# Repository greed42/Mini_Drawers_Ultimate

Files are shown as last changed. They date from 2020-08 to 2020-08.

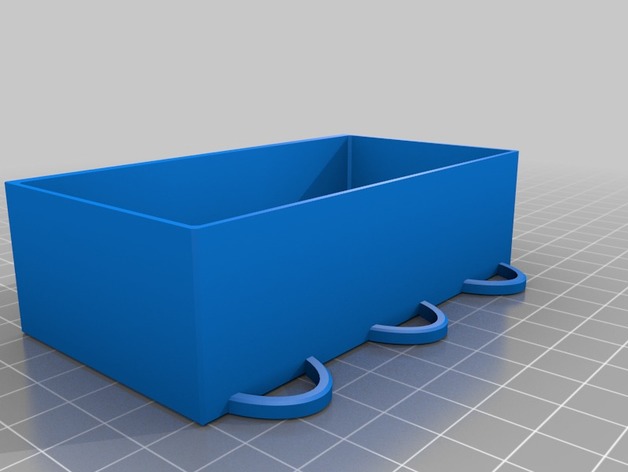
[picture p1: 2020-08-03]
images/7e2ca545eac1c5725b5ad3fc7ff9e364_preview_featured.jpg

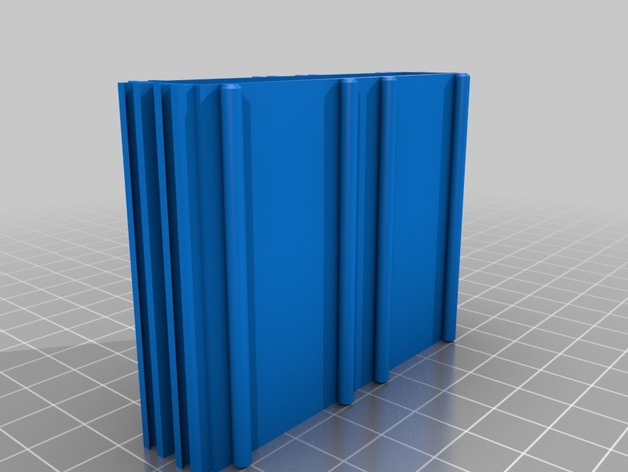
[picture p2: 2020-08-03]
images/3b2bb9709fd0cc8f3b78cd49e6e431dc_preview_featured.jpg

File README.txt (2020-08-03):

                   .:                     :,                                          
,:::::::: ::`      :::                   :::                                          
,:::::::: ::`      :::                   :::                                          
.,,:::,,, ::`.:,   ... .. .:,     .:. ..`... ..`   ..   .:,    .. ::  .::,     .:,`   
   ,::    :::::::  ::, :::::::  `:::::::.,:: :::  ::: .::::::  ::::: ::::::  .::::::  
   ,::    :::::::: ::, :::::::: ::::::::.,:: :::  ::: :::,:::, ::::: ::::::, :::::::: 
   ,::    :::  ::: ::, :::  :::`::.  :::.,::  ::,`::`:::   ::: :::  `::,`   :::   ::: 
   ,::    ::.  ::: ::, ::`  :::.::    ::.,::  :::::: ::::::::: ::`   :::::: ::::::::: 
   ,::    ::.  ::: ::, ::`  :::.::    ::.,::  .::::: ::::::::: ::`    ::::::::::::::: 
   ,::    ::.  ::: ::, ::`  ::: ::: `:::.,::   ::::  :::`  ,,, ::`  .::  :::.::.  ,,, 
   ,::    ::.  ::: ::, ::`  ::: ::::::::.,::   ::::   :::::::` ::`   ::::::: :::::::. 
   ,::    ::.  ::: ::, ::`  :::  :::::::`,::    ::.    :::::`  ::`   ::::::   :::::.  
                                ::,  ,::                               ``             
                                ::::::::                                              
                                 ::::::                                               
                                  `,,`

http://www.thingiverse.com/thing:1889761
Mini Drawers Ultimate by zeropage is licensed under the Creative Commons - Attribution - Non-Commercial - Share Alike license.
http://creativecommons.org/licenses/by-nc-sa/3.0/

# Summary

__What is this thing?__
This is a remix of TrevM's [Mini Drawers](http://www.thingiverse.com/thing:1621667 "Mini Drawers"). The original design is great but I needed some improvements. Thankfully, TrevM provides the *.scad-files, so the required changes could be made using OpenSCAD:

-     The runners did not fit perfectly in the slots. I think it depends on your 3D printer how snuggly these pieces fit together. I added a global variable "runnersDiameter" to the corresponding *.scad-files so adjusting the runner's diameters is quiet easy. I was fine with 2.85mm.

-   To prevent the drawers from falling out when pulling too far I added a small stopper on the top/front inside of the house.

-   Added magnet holes to the house's and drawer's backside. While the aforementioned stopper prevents pulling a drawer too far, the magnets prevent the drawer from sliding when a house is moved or tilted.

-   The handles were too delicate for my fingers so I made them oval and increased their protrusion.

-   To minimize elephant feet I added chamfers to the bottom of the drawer and handle using the [Chamfered primitives for OpenSCAD](https://github.com/SebiTimeWaster/Chamfers-for-OpenSCAD/ "Chamfered primitives for OpenSCAD") library by TimeWaster.

-  
Finally, a plethora of different sized houses and drawers is available. If the ones provided are not enough, read below in the Logbook how to create arbitrarily sized boxes.

See the chapter below for print instructions. And see the chapter post-printing on instructions for mounting the magnets (I used magnets similar to [these](https://www.aliexpress.com/item/50Pcs-8x1-Neodymium-Magnet-Disc-Permanent-N35-NdFeB-Small-Round-Super-Powerful-Strong-Magnetic-Magnets-8mm/32866508617.html) from AliExpress.)

Tell me if you need help or something specific!

__ __

__Logbook__
- *26.11.2017* -- Added new sizes 2x3 and the whole 3x1 .. 3x3 series. Mission complete.
- *09.10.2017* -- Reworked the filenames. Added missing houses/drawers like the 2x1 magnet versions. Added new sizes 1x3 and 2x2.
Right now, we have 1x1, 1x2, 1x3 as well as 2x1 and 2x2 houses and drawers each as a magnet and non-magnet version.✓ Soon I will add 2x3 as well as the whole 3x1..3 series, so there will be some big badda boom boxes available. For even bigger sizes or houses and drawers with slot-in magnets please use the Scad-files to produce the required STLs (see next Log-entry).

- *09.10.2017* -- Finally! Added three Scad-files that allow you to create arbitrarily sized houses and drawers with or without magnets *and* you can choose whether you have the standard glue-in magnet slots or -new!- drop-in magnet slots.
_All praise has to go to [@ofloveandhate](https://www.thingiverse.com/ofloveandhate/about) who rewrote the original code to enable the aforementioned parametrizations. Dani, thanks a lot!_
Please note that this is work in progress and that you need to use OpenScad to create your own STL-files!
How to: Use "assembly.scad" to produce a house and an accompanying drawer at the same time. Very important: If you choose drop-in magnets, you *must* edit the "house.scad" and uncomment a couple of lines of code. Read the comments carefully.

- *24.05.2017* -- Added a 1x1 drawer with three slots (magnet and non-magnet version).

- *09.05.2017* -- Added a 2x1 house and drawer. Thanks to Elerion for beta printing! And a good tip from Elerion for those whose printers produce drawers that are too tightly fitting: Reduce the drawers' sizes by 1% on the X and Z axes. Magnet versions of the 2x1 set tbd.

- *23.01.2017* -- My drawers glided too easily in their houses with the result that they tended to slide open when my drawer phalanx was (accidentally) touched. Or, much worse, nuts, screws, and other stuff got spilled over my table. Since I already printed a lot of houses and drawers, I underwent the pain to drill a plethora of 8mm holes to glue 8mm x 1mm magnets to the backside of the houses and drawers. See [this video](https://youtu.be/GgcQiEWDeZY) how the houses/drawers with magnets work and look like.
To ease things for the future, all MD Ultimate files are now available in two versions: With and without holes for 8mm x 1mm magnets! (I used [these](https://www.aliexpress.com/item/50Pcs-Silver-N35-Super-Strong-Round-Disc-8mm-X-1mm-Rare-Earth-Neodymium-magnet/32704942674.html) magnets from AliExpress.)

- *31.12.2016* -- A double sized drawer with divider was missing. masterman274 was so kind to provide [this one](http://www.thingiverse.com/thing:2006275). Thank you! (Please note that I added an according drawer in the meantime while dealing with the magnet stuff; cf. above.)

-
*15.11.2016* -- Added a drawer with two slots.

# Print Settings

Printer Brand: Ultimaker
Printer: Ultimaker 2
Resolution: 0.16mm
Infill: 0%

Notes: 
Some notes on printing: I tried a lot of different settings (in Cura) to optimise quality and print speed. My best settings with a 0.4mm nozzle so far:

- Layer height 0.16mm
- Shell thickness 0.4 mm
- Bottom/top thickness 0.8mm
- Fill density 0% (yes, zero!)
- Print speed 70 mm/s
- no support, no brim

A word on zero infill: Since neither the houses nor the drawers will -in most cases- experience a lot of stress they, thus, do not need to be rock solid. Using zero infill with a shell thickness of 0.4mm is kind of spiralizing the inner and outer walls and only filling the top and bottom. This results in reduced printing times and a sufficient strength.

# Post-Printing

## How to attach the magnets

If you printed houses and drawers with mounting holes for magnets you might ask yourself how to attach the magnets to these holes.

I put a drop of super glue on the rim of a magnet, laid it down on my workbench, then imposed the house (or drawer) on the magnet. This way, the magnet and the house or drawer will be on level. Take care that leaking super glue may glue your house or drawer to the workbench. To avoid this I moved the house or drawer in a circular motion. Just long enough until the magnet was sufficiently sticking to the house or drawer.

Another option might be to put a drop of hot glue on the magnet, then impose the house or drawer on the magnet. Hot glue allows minor corrections by gently heating up the glue. Nonetheless, take care not to take too much hot glue since you do not want the glue to get in the way with the drawer.

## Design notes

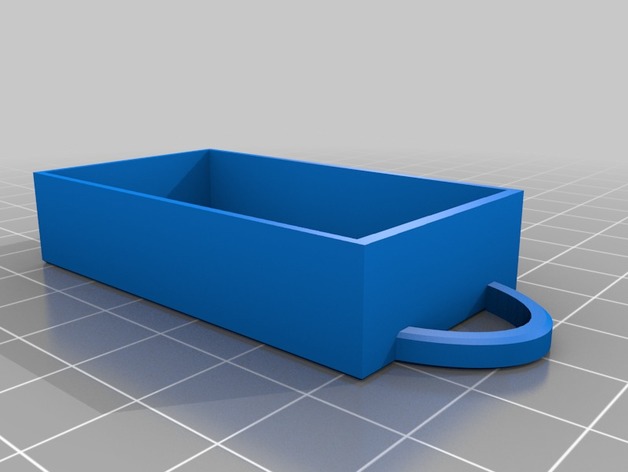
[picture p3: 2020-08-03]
images/46b5443ca9f86b0492274a63288024b4_preview_featured.jpg

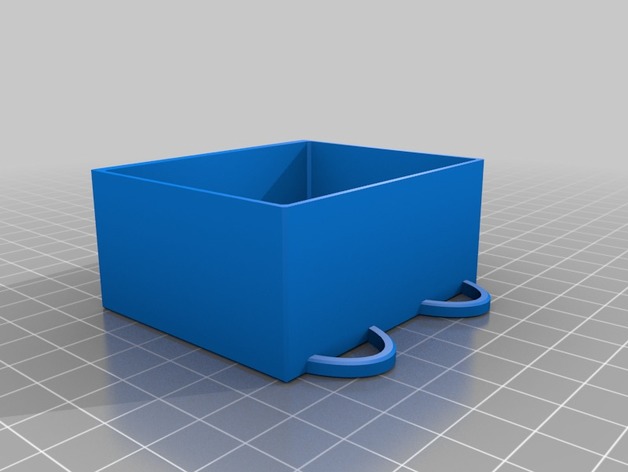
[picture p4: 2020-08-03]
images/7ca578415db62366bc3f32fe54b87f35_preview_featured.jpg

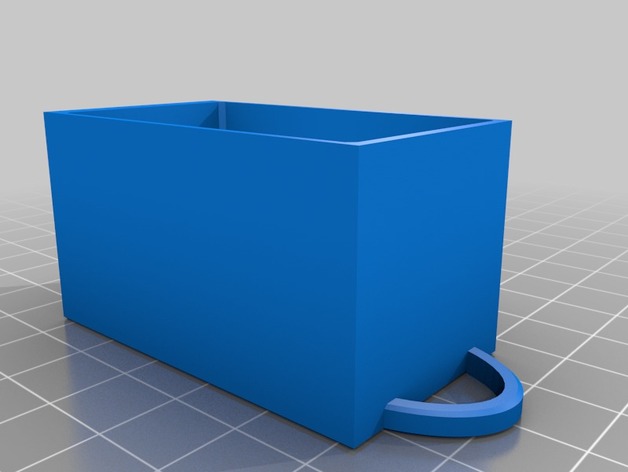
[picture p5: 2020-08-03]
images/18cb1cac1b9d0c3dc831ad14e947cb29_preview_featured.jpg

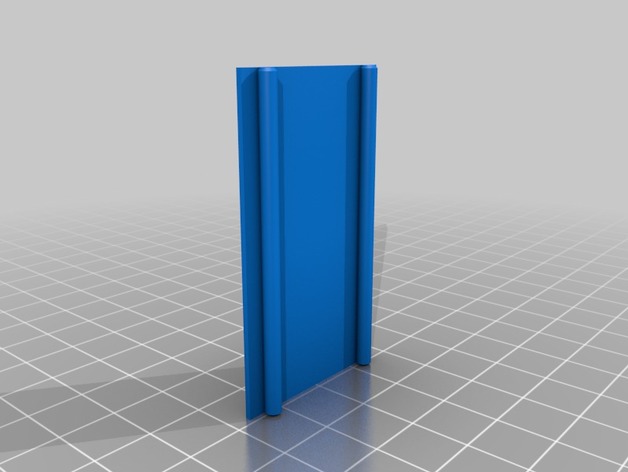
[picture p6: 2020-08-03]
images/90e3aa6325cb6bdf091ba50e56fa240c_preview_featured.jpg

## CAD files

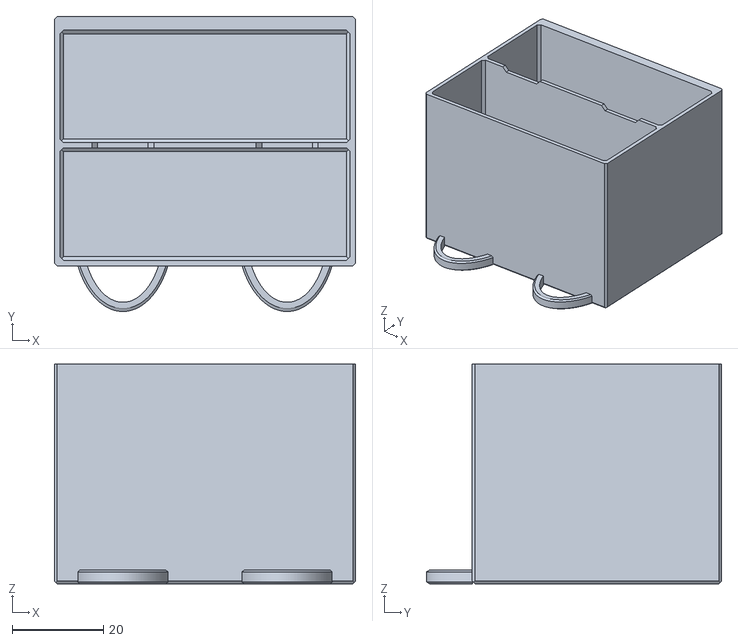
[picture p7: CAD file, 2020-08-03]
files/2x3_Drawer_-_two_slots_magnet.stl
65.9 x 64.5 x 48.0

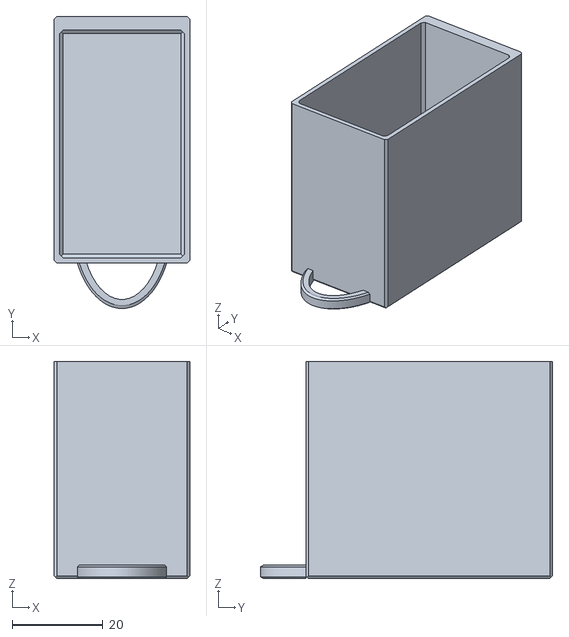
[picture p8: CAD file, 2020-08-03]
files/1x3_Drawer_magnet.stl
30.0 x 64.5 x 48.0

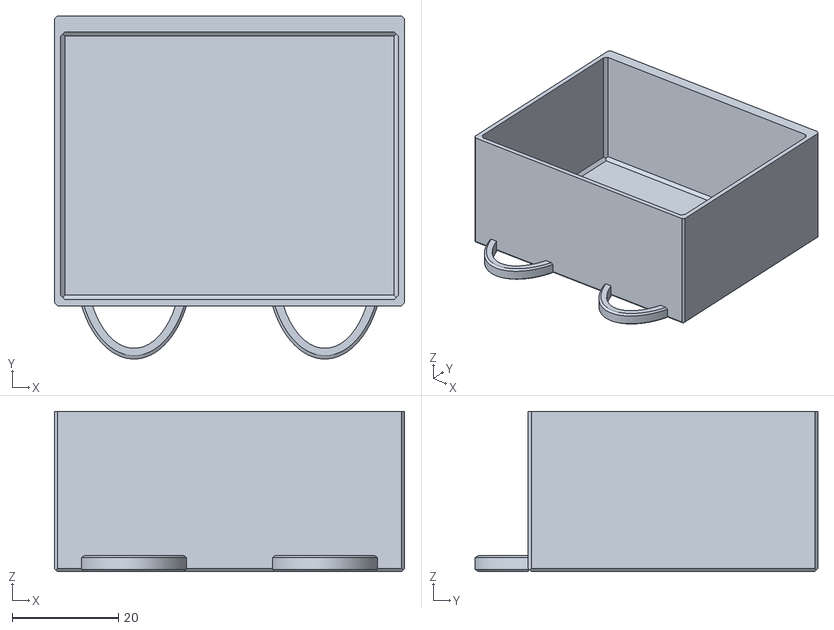
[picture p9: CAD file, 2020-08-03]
files/2x2_Drawer.stl
65.9 x 64.5 x 30.1

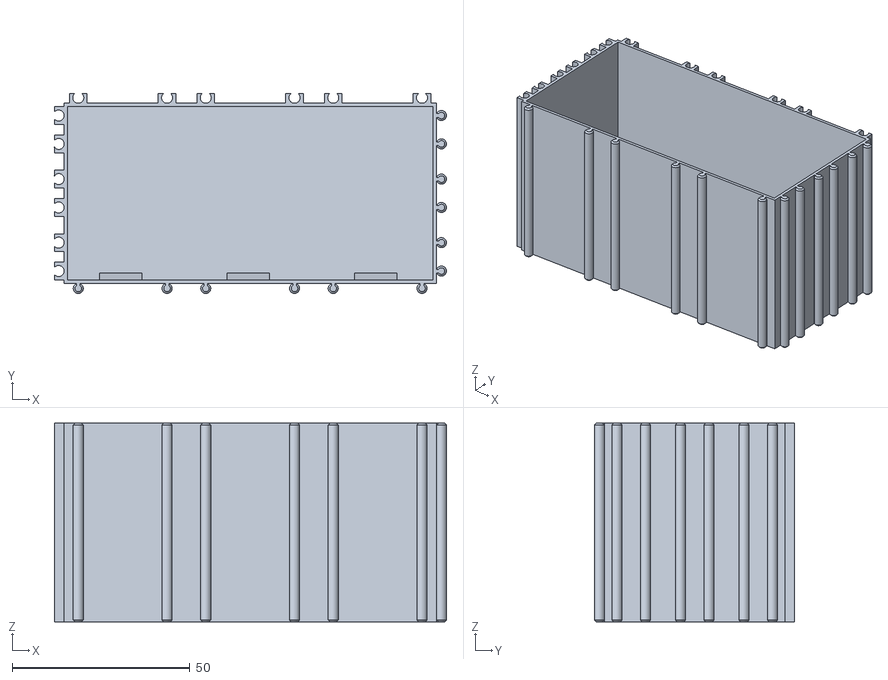
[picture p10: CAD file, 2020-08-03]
files/3x3_House.stl
110.4 x 56.3 x 56.0

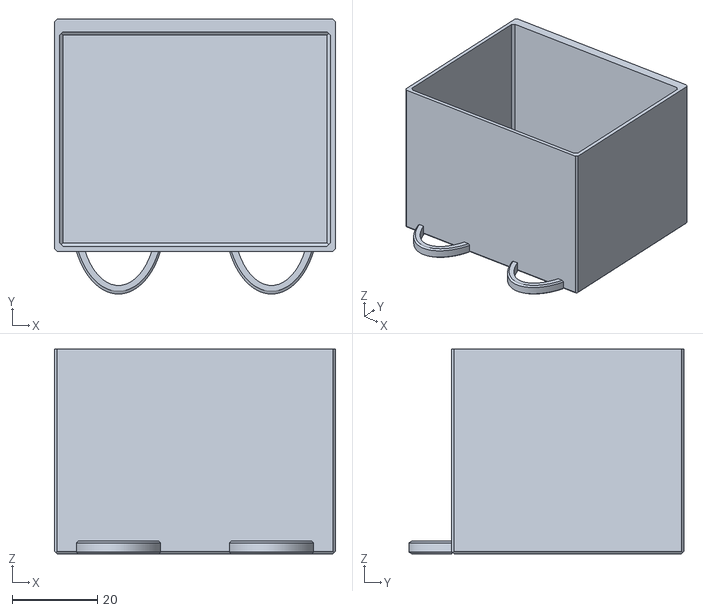
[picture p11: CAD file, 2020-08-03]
files/2x3_Drawer_magnet.stl
65.9 x 64.5 x 48.0

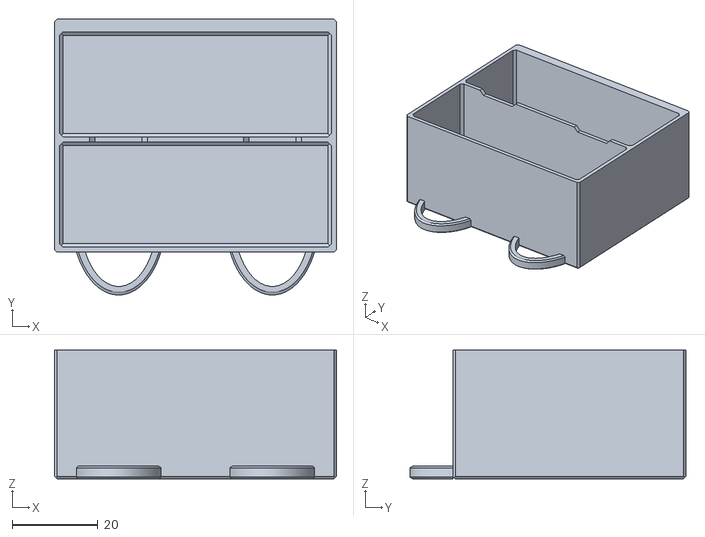
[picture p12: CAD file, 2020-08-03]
files/2x2_Drawer_-_two_slots.stl
65.9 x 64.5 x 30.1

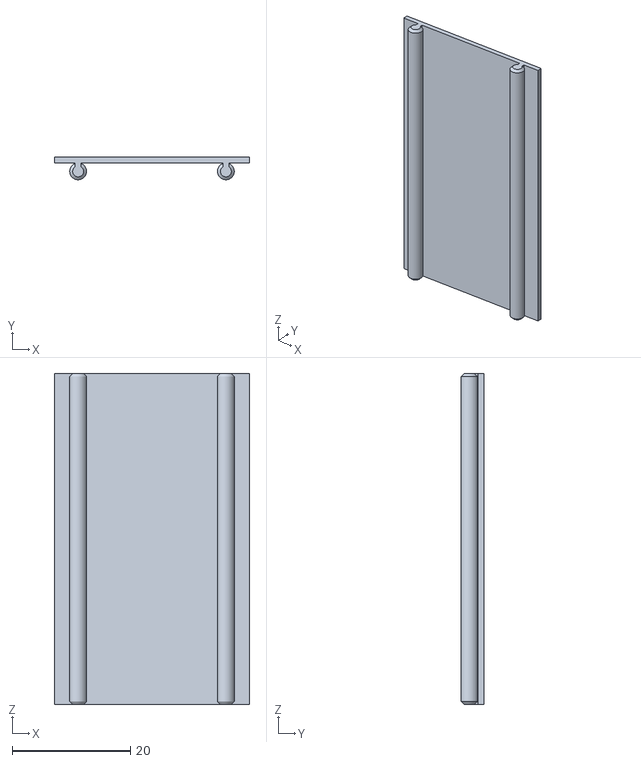
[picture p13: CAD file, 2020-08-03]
files/1x1_House_-_bottom_plate.stl
33.0 x 3.82 x 56.0

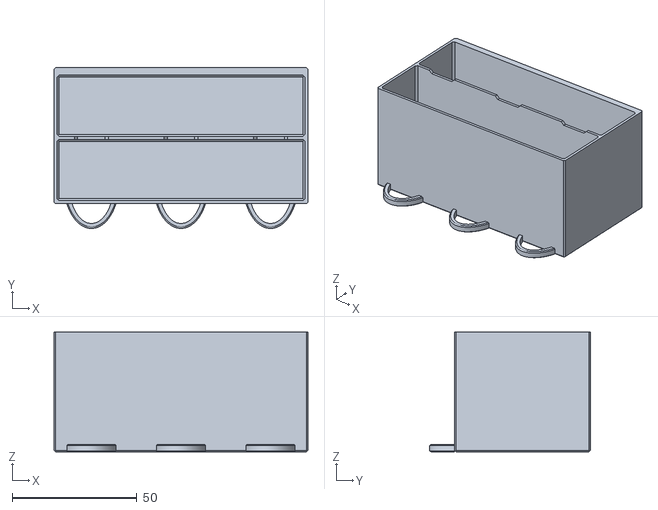
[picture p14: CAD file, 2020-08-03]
files/3x3_Drawer_-_two_slots.stl
101.8 x 64.5 x 48.0

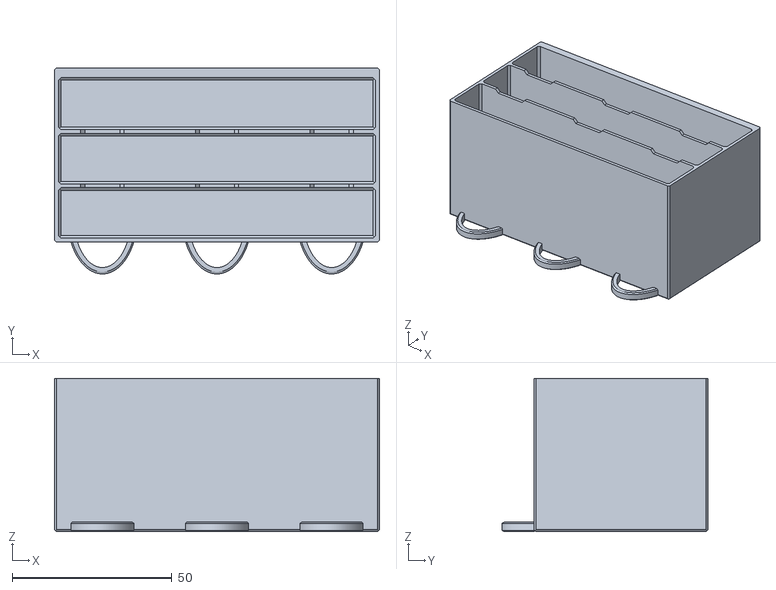
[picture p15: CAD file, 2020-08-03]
files/3x3_Drawer_-_three_slots_magnet.stl
101.8 x 64.5 x 48.0

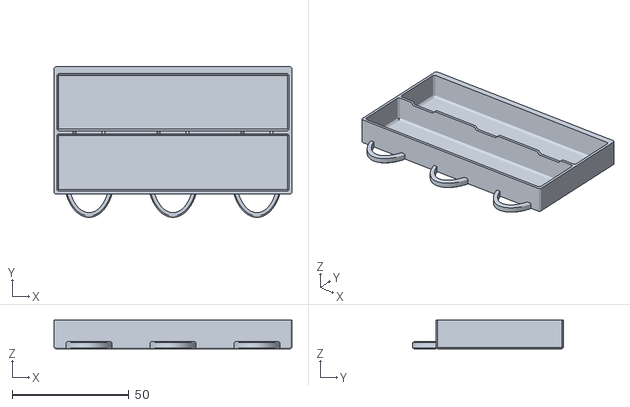
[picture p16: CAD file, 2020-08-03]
files/3x1_Drawer_-_two_slots.stl
101.8 x 64.5 x 12.2

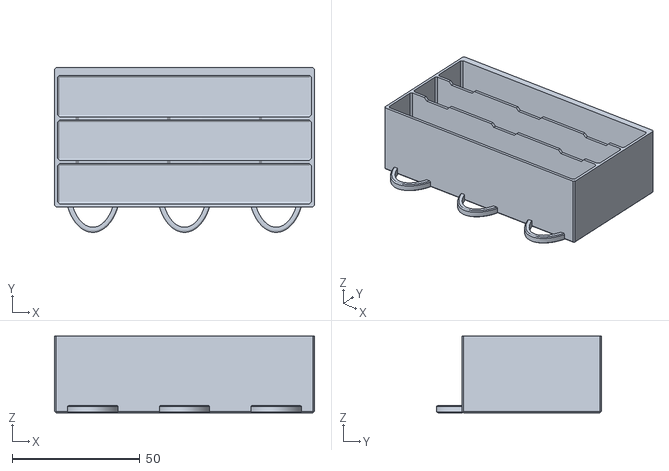
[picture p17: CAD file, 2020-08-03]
files/3x2_Drawer_-_three_slots_magnet.stl
101.8 x 64.5 x 30.1

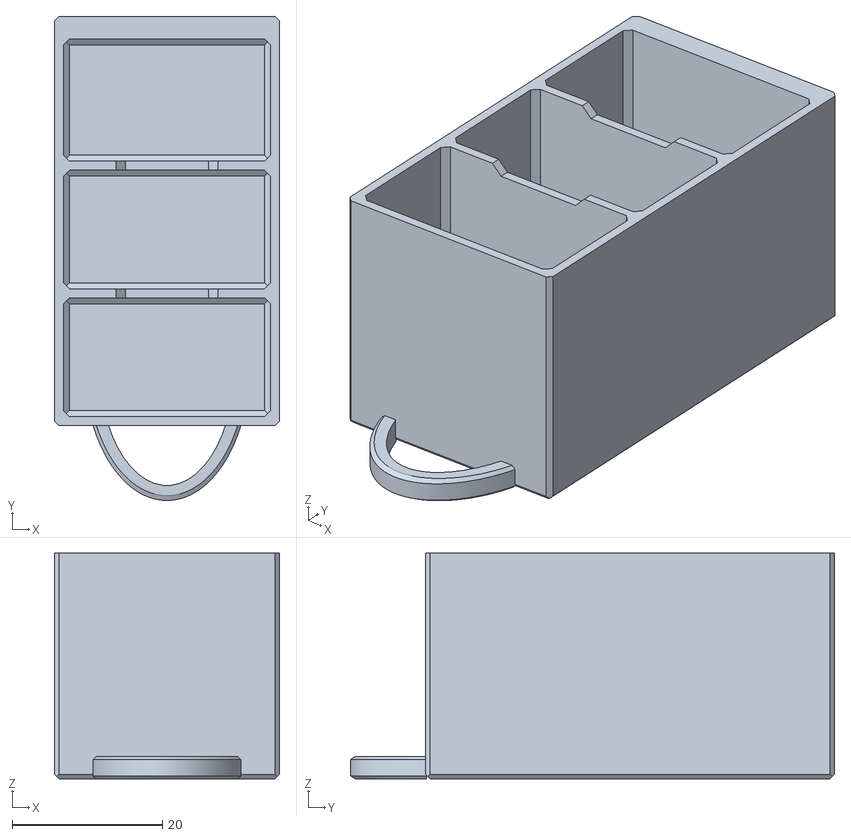
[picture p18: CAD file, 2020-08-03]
files/1x2_Drawer_-_three_slots_magnet.stl
30.0 x 64.5 x 30.1

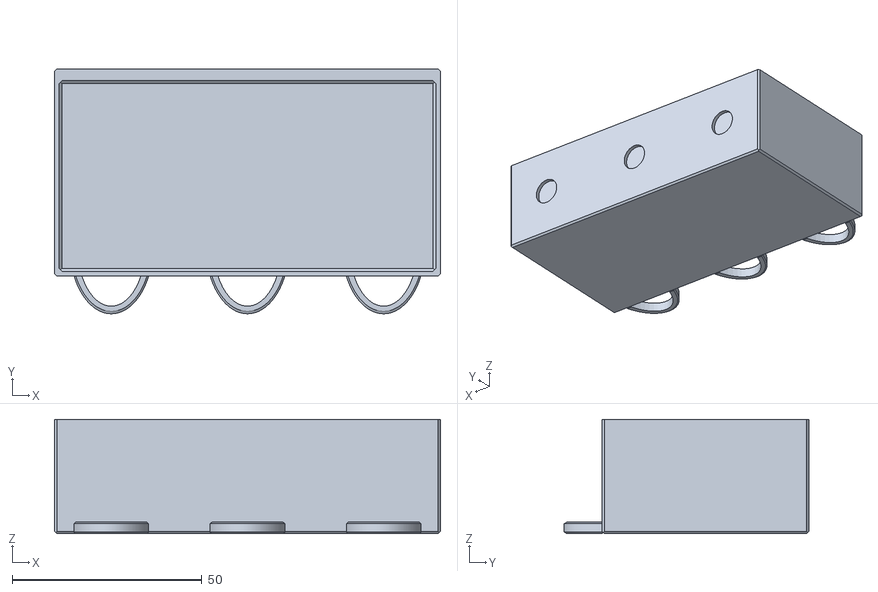
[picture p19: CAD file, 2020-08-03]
files/3x2_Drawer_magnet.stl
101.8 x 64.5 x 30.1

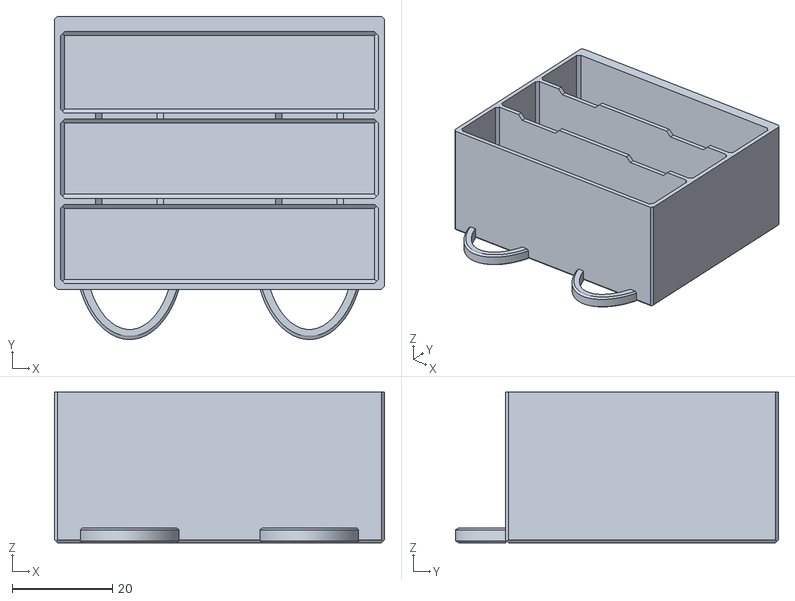
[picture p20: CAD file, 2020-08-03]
files/2x2_Drawer_-_three_slots.stl
65.9 x 64.5 x 30.1

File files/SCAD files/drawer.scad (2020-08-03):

// scad code for modular minidrawer -- drawer part
// code originally by zeropage. rewritten by ofloveandhate sep2017

include <Chamfer.scad>; // https://github.com/SebiTimeWaster/Chamfers-for-OpenSCAD/

drawer_label = ["test",4,"Liberation Sans:style=Bold",0.5];
use_label = true;

$fn = 50;
ang = 25;

// ======= EDIT ======================
num_x = 1;
num_y = 2;
slot_partition = [.33,.33, .34];//[0.4,0.6]; // partition of 1 into slots
use_magnet = false;
magnet_is_droppedin = false;
// ===================================

// ideally these numbers come directly from the house parameters.
house_wall_thickness_s = 1;
house_wall_thickness_b = 1;
house_depth = 56;
unit_height = 17.9;
unit_width = 35.9;
space_width = 4.9;
space_height = 4.9;


// thicknesses of things
drawer_wall_thickness_x = 1.2;
drawer_wall_thickness_f = 1.2;
drawer_wall_thickness_b = 3; // shoule be thicker than magnet_h plus extrusions, if using slot for magnet
drawer_wall_thickness_s = 1.2; // thickness of walls between slots
drawer_floor_thickness = 1;

// space to leave between the walls of the drawer and house
inset_width = 0.5;
inset_height = 0.6;
inset_depth = 0.5;



chamfer_interior = 0.8;
chamfer_exterior = 0.6;
should_chamfer_top = 0; // a boolean 1 or 0

magnet_r = 4.15;
magnet_h = 1.25;

use_num_x_handles = true; // false generates a single handles in the middle

eps = 0.01;





to_print = true;

if (to_print)
{
  translate([0,-drawer_depth-10,0])
  drawer();
}
else
  ;


module drawer()
{
  difference()
  {
    drawer_positive();
    drawer_negative();
  }

  handles(); 
}

drawer_depth = house_depth - 1*house_wall_thickness_b - inset_depth;// including walls
drawer_width = unit_width*num_x -space_width - 2*inset_width;
drawer_height = unit_height*num_y - space_height+0.8 - inset_height;

module drawer_positive()
{
  usable_height = drawer_height - drawer_floor_thickness;
  chamferCube(drawer_width,drawer_depth,usable_height,chamfer_exterior,[1,1,should_chamfer_top,should_chamfer_top],[1,should_chamfer_top,should_chamfer_top,1],[1,1,1,1]); 
  if ( use_label ) label();
}

module drawer_negative()
{

  num_slots = len(slot_partition);

  interior_w = drawer_width - 2*drawer_wall_thickness_x;

  x = drawer_wall_thickness_f;

  usable_depth = drawer_depth - drawer_wall_thickness_f - drawer_wall_thickness_b - (
  num_slots-1)*drawer_wall_thickness_s;

  usable_height = drawer_height - drawer_floor_thickness;

  for (ii = [0:num_slots-1])
  {
    depth_this = slot_partition[ii]*usable_depth;
    y_this = 0;
    used_prev = add(slot_partition, 0, num_slots-ii);
    bla = used_prev*usable_depth+ii*drawer_wall_thickness_s + drawer_wall_thickness_f;

    translate([drawer_wall_thickness_x,bla,drawer_floor_thickness])
      chamferCube(interior_w,depth_this,usable_height,chamfer_interior,[1,1,0,0],[1,0,0,1],[1,1,1,1]);
  }

  if (num_slots>1)
  {
    for (jj = [0:num_x-1]){
      for (ii = [1:num_slots-1])
      {
        depth_this = slot_partition[ii]*usable_depth;
        y_this = 0;
        used_prev = add(slot_partition, 0, num_slots-ii);
        //		echo(used_prev);
        bla = used_prev*usable_depth+ii*drawer_wall_thickness_s + drawer_wall_thickness_f - drawer_wall_thickness_s*1.5;
        //drawer_width/(num_x)*(jj) + 14/2
        translate([8 +jj*35.9,bla,usable_height-1.29])
        {
          chamferCube(14,2,1.3,1.5,[],[1,0,0,1],[]);
        }
      } // for ii
    } // jj
  } // if
  if (use_magnet)
    drawer_magnet_cutouts();
}

function add(cont, ii=0, off_b=0, val=0) = ii<len(cont)-off_b ? add(cont, ii+1, off_b, val+cont[ii]) : val;

module drawer_magnet_cutouts()
{
  for (ii = [0:num_x-1])
  {
    if (magnet_is_droppedin)
      translate([ii*35.9+15,drawer_depth - drawer_wall_thickness_b/2-magnet_h/2,0])
        drawer_magnet_cutout_single();
    else
      translate([ii*35.9+15,drawer_depth-magnet_h+eps,0])
        drawer_magnet_cutout_single();
  }	
}



module drawer_magnet_cutout_single()
{
  translate([0,0,drawer_height/2]) 
  {
    translate([0,0,0])
      rotate([-90,0,0]) cylinder(h=magnet_h+eps,r=magnet_r,$fn=100); // top hole for magnet
    if (magnet_is_droppedin)
      translate([-magnet_r,-eps,0])
        cube([magnet_r*2, magnet_h+2*eps, drawer_height/2]); // top hole for magnet
  }

}

module handles()
{
  if (use_num_x_handles)
  for (ii=[0:num_x-1])
    translate([ii*35.9+15,0,0])
      handle();
  
  else
     translate([drawer_width/2,0,0])
      handle();
}


module handle()
{
  difference() {
    translate([0,8,0]) chamferOval(11,18,3);
    translate([0,8,-0.1]) oval(9,16,3.2);
    translate([-11-2,0.1,-0.1])	cube([29.8,30,3.2]);
  }
}

module oval(w,h, height, center = false) {
  scale([1, h/w, 1]) cylinder(h=height, r=w, center=center);
}

module chamferOval(w,h, height) {
  scale([1, h/w, 1]) chamferCylinder(height, w, w, .4, 360,1);
}


module label()
{
/* original code from dani      translate([drawer_width/2-len(drawer_label[0])/2*drawer_label[1]*0.6,0,drawer_height/2])
    rotate([90,0,0])
      linear_extrude(height=drawer_label[3])
        text(drawer_label[0], font=drawer_label[2], size=drawer_label[1]);
*/    
/* as suggested by Bolukan */
translate([drawer_width/2,0,drawer_height/2+0.75])
rotate([90,0,0])
linear_extrude(height=drawer_label[3])
text(drawer_label[0], font=drawer_label[2], size=drawer_label[1], halign="center", valign="center");    
}

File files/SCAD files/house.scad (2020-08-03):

// scad code for modular minidrawer -- house part
// code originally by zeropage. rewritten by ofloveandhate sep2017

include <Chamfer.scad>; // https://github.com/SebiTimeWaster/Chamfers-for-OpenSCAD/
$fn = 50;
house_wall_thickness_b = 1;
house_depth = 56; // in millimeters. this is the depth of the unit against the wall, front to back, including walls.

// ======= EDIT ================
num_x = 2;  // width
num_y = 2;  // height
use_magnet = false; // true to use magnets
//magnet_is_droppedin = true; // true to get drop-in slot for the magnet
//house_wall_thickness_b = 2; // MUST uncomment if drop-in magnets used, else the backwall will be too thin
//house_depth = 57; // MUST uncomment if drop-in magnets used, else the drawers will stand out by 1mm
magnet_r = 4.15;
magnet_h = 1.25; // the back wall should be at least this thick if using dropped in magnet
// ===============================

house_wall_thickness_s = 1;

interior_unit_width = 35.9;
interior_unit_height = 17.9;

chamfer_runners = 0.5;
runnersDiameter = 2.85;
runner_joincube_width = 1;

slot_thickness = 2.8;
slot_width = 5;
slot_gap = 0.25 ; // extra space between the runner cylinder, and the slot receiver. this number is a difference in diameters, so this difference is NOT the total gap all around, that's half this number.
slot_cylinder_inset = 0.1;
slot_inset_from_box_x = 1.5;
slot_inset_from_box_y = 1;

runner_offset_x = 25;
runner_offset_y = 8;

stopper_height = 2;  // how far off the top wall the stopper should project
stopper_length = 10;
stopper_width = 10;
stopper_inset = 2;
stopper_faces_front = false;  // which side the flat face of the stoppers should be on.  if true, the flat face is toward the front of the housing.


eps = 0.01;

to_print = true;




///////////utility computations

inter_house_offset = house_wall_thickness_s*2 + runnersDiameter; // 4.9 is old version
house_box_height = num_y*interior_unit_height - inter_house_offset; 
house_box_width = num_x*interior_unit_width - inter_house_offset; 
inter_drawer_offset = (runnersDiameter+slot_gap/2);

////////////  end utility computations


if (to_print)
  house();
else
{
//  house(); // display mode in the assembly

//  translate([-house_box_width - inter_house_offset,0,0])
//    house();
//
//  translate([house_box_width + inter_house_offset,0,0])
//    house();
//
//  translate([0,-house_box_height - inter_house_offset,0])
//    house();
//
//  translate([0,+house_box_height + inter_house_offset,0])
//    house();
}

module house()
{
  difference() {
    house_positive();
    house_negative();
  }
}


module house_negative()
{
  q = house_wall_thickness_s*2 + runnersDiameter; // 4.9 for 100% compatibility w old versions
  difference(){
    translate([house_wall_thickness_s,house_wall_thickness_s,house_wall_thickness_b])
      cube([interior_unit_width*num_x-q, interior_unit_height*num_y-q, house_depth]);
    stoppers();
  }
  if (use_magnet)
    house_magnet_cutouts();
}


module house_magnet_cutouts()
{
  if (magnet_h >= 1*house_wall_thickness_b && magnet_is_droppedin)
  {
    echo("magnet thickness very near to back wall thickness.  things probably not as desired");
  }

  for (ii = [0:num_x-1])
  {
    if (magnet_is_droppedin)
    {
      translate([ii*interior_unit_width+16,0,house_wall_thickness_b/2-magnet_h/2])
        magnet_cutout_single();
    }
    else
    {
      translate([ii*interior_unit_width+16,0,house_wall_thickness_b-magnet_h])
        magnet_cutout_single();
    }
  }	
}



module magnet_cutout_single()
{
  translate([0,house_box_height/2, 0 ])
  {
    magnet();
    if (magnet_is_droppedin)
    {
      magnet_cutout_slot();
    }
  }
}

module magnet()
{
  translate([0,0,0])
    rotate([0,0,0]) cylinder(h=magnet_h+eps,r=magnet_r,$fn=100);
}

module magnet_cutout_slot()
{
  c = house_box_height/2+2*eps;
  translate([-magnet_r,-house_box_height/2-eps,0])
    cube([magnet_r*2, c , magnet_h+eps ]); // top hole for magnet
  // the eps here are to ensure the cube protrudes from the top of the house
}



module stoppers()
{
for (ii = [0:num_x-1])
  translate([ii*interior_unit_width,0,0]) 
    stopper();
}

module stopper()
{
  translate([stopper_width,stopper_height+house_wall_thickness_s-eps,house_depth-stopper_inset]) 
    rotate( [0,180,180] ) 
      prism(l=stopper_length+stopper_height,w=stopper_height,h=stopper_length);
}



module house_positive()
{
  q = runnersDiameter; // 2.9 for 100% compatibility with old versions, though the difference is quite small (0.05)

  overall_x = interior_unit_width*num_x-q;
  overall_y = interior_unit_height*num_y-q;
  cube([overall_x, overall_y,house_depth]); 

  radius = runnersDiameter/2;

  for (ii=[0:num_x-1])
    translate([interior_unit_width*ii,0,0])
    {
      runner_bottom();
      translate([runner_offset_x, 0, 0])
        runner_bottom(); 

      translate([0,overall_y-interior_unit_height+q,0])
      {
        slot_top();
        translate([runner_offset_x,0,0])
          slot_top();
      }
    }

  for (jj=[0:num_y-1])
    translate([0,interior_unit_height*jj,0])
    {
      translate([overall_x-(interior_unit_width-runnersDiameter),0,0])
      {
        runner_right();
        translate([0,8,0])
          runner_right(); 
      }
      translate([0,0,0])
      {
        slot_left();
        translate([0,runner_offset_y,0])
          slot_left();
      }
    } // for jj's translate

}




module slot_top()
{
  slot_diameter = runnersDiameter + slot_gap;
  difference()
  {
    translate([ slot_inset_from_box_x,  15-slot_cylinder_inset, 0]) cube([slot_width,slot_thickness,house_depth]);
    translate([ (slot_width/2+slot_inset_from_box_x),  16.5, -eps]) cylinder(d=slot_diameter,h=house_depth+2*eps);
  }
}

module runner_bottom()
{
  runner_cylinder_inset_bottom = 0.025;
  radius = runnersDiameter/2;

  x = slot_width/2+slot_inset_from_box_x;
  y = radius-runner_cylinder_inset_bottom;

  translate([ x,  -y, 0]) chamferCylinder(house_depth,radius,radius,chamfer_runners);
  translate([x-runner_joincube_width/2,-(y-eps), 0]) cube([runner_joincube_width,radius,house_depth]);
}


module slot_left()
{
  slot_diameter = runnersDiameter + slot_gap;
  translate([0,0,0])
  difference()
  {
    q = runnersDiameter/2+slot_cylinder_inset;
    translate([- (slot_thickness - slot_cylinder_inset),   slot_inset_from_box_y,   0]) cube([slot_thickness,slot_width,house_depth]);
    translate([-q, slot_inset_from_box_y + slot_width/2, -eps]) cylinder(d=slot_diameter,h=house_depth+2*eps);
  }

}


module runner_right()
{

  radius = runnersDiameter/2;
  translate([(interior_unit_width-runnersDiameter/2), slot_inset_from_box_y + slot_width/2,0]) chamferCylinder(house_depth,radius,radius,chamfer_runners);

  x = (interior_unit_width-runnersDiameter)-eps;
  y = slot_inset_from_box_y + slot_width/2-runner_joincube_width/2;
  translate([x, y,  0]) cube([radius,runner_joincube_width,house_depth]);
}







module prism(l, w, h)
{
  p_front = [[0,0,0], [l,0,0], [l,w,0], [0,w,0], [0,w,h], [l,w,h]];
  p_back = [[0,0,h], [l,0,h], [l,w,0], [0,w,0], [0,w,h], [l,w,h]];

  f = [[0,1,2,3],[5,4,3,2],[0,4,5,1],[0,3,4],[5,2,1]];

  if (stopper_faces_front)
  {
    polyhedron(
      points=p_front,
      faces=f
    ); 
  }
  else
  {
    polyhedron(
      points=p_back,
      faces=f
    ); 
  }

}

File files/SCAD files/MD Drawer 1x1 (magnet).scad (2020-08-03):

include <Chamfer.scad>;

$fn = 50;
ang = 25;

translate([ -15,0,0]) drawer0();

module drawer0()
{
  difference() {
	chamferCube(30.4,54.1,12.4,.4,[1,1,0,0],[1,0,0,1],[]);
    translate([1,1.5,1]) cube([28.4,49,23]);
//    translate([1,1.5,1]) chamferCube(28.4,51,13,2,[1,0,0,0],[],[]);
    translate([15,54.2,5.5]) rotate([90,0,0]) cylinder(h=1.25,r=4.15,$fn=100);
  }
  handle();
}

module handle()
{
  difference() {
    translate([15,8,0]) chamferOval(11,18,3);
    translate([15,8,-0.1]) oval(9,16,3.2);
    translate([0.1,0.1,-0.1]) cube([29.8,30,3.2]);
  }
}

module oval(w,h, height, center = false) {
  scale([1, h/w, 1]) cylinder(h=height, r=w, center=center);
}

module chamferOval(w,h, height) {
  scale([1, h/w, 1]) chamferCylinder(height, w, w, .4, 360,1);
}

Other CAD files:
files/2x2_Drawer_magnet.stl
files/2x3_Drawer.stl
files/2x3_Drawer_-_three_slots_magnet.stl
files/1x1_Drawer_magnet.stl
files/SCAD files/MD Drawer 1x1 three slots (magnet).scad
files/1x1_Drawer.stl
files/1x1_Drawer_-_three_slots.stl
files/1x1_Drawer_-_three_slots_magnet.stl
files/1x1_Drawer_-_two_slots.stl
files/1x1_Drawer_-_two_slots_magnet.stl
files/1x1_House.stl
files/1x1_House_magnet.stl
files/1x2_Drawer.stl
files/1x2_Drawer_-_three_slots.stl
files/1x2_Drawer_-_two_slots.stl
files/1x2_Drawer_-_two_slots_magnet.stl
files/1x2_Drawer_magnet.stl
files/1x2_House.stl
files/1x2_House_magnet.stl
files/1x3_Drawer.stl
files/1x3_Drawer_-_three_slots.stl
files/1x3_Drawer_-_three_slots_magnet.stl
files/1x3_Drawer_-_two_slots.stl
files/1x3_Drawer_-_two_slots_magnet.stl
files/1x3_House.stl
files/1x3_House_magnet.stl
files/2x1_Drawer.stl
files/2x1_Drawer_-_three_slots.stl
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

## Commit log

2020-08-03 Import contents of zip file
    From "Download all files" on https://www.thingiverse.com/thing:1889761 as
    of 2020-07-28.
    [1x1_Drawer.stl, 1x1_Drawer_-_three_slots.stl, 1x1_Drawer_-_three_slots_magnet.stl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]
2020-08-03 Unpack nested ZIP file
    [MD Drawer 1x1 (magnet).scad, MD Drawer 1x1 three slots (magnet).scad, MD Drawer 1x1 three slots.scad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]
